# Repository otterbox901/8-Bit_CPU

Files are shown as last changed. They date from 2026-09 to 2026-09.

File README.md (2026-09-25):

# 8-Bit CPU

A microcoded 8-bit CPU built from 24 74HC-series logic and memory ICs: custom
instruction set, 4 general-purpose registers, add/subtract ALU with Zero and
Carry flags, and a control unit driven entirely by two EEPROMs.


*Preview from JLCPCB

## Status: In progress

- [x] Instruction set (10 instructions, 1- and 2-byte encodings)
- [x] Microcode ROM generator (`ROM/microcode_rom_gen.py`)
- [x] Emulator + assembler, full test program passing
- [x] Schematic: 24 ICs, 0 ERC errors
- [x] Schematic verified by simulation: the KiCad netlist runs the test program
      at the chip-pin level with the real ROM images (`kicad_files/sim_netlist.py`)
- [x] PCB: 2-layer, 160 × 140 mm, fully routed (Freerouting), GND pour on
      both layers; DRC clean (0 errors, 0 warnings, 0 unconnected) and 0
      schematic-parity differences
- [x] Fabrication outputs: Gerbers + drill (`fab/8-bit-cpu-gerbers.zip`),
      BOM and pick-and-place files
- [ ] Order boards, burn the EEPROMs, and bring up the hardware

## Overview

| | |
|---|---|
| Data path | 8-bit |
| Registers | R0–R3 (2 × 74HC670 register file), plus PC, MAR, IR, A, TEMP |
| Control unit | Microcoded: 2 × 28C256, addressed by opcode, 2-bit step, Z, C |
| ALU | Add, subtract (two's complement), Zero and Carry flags |
| Memory | Harvard: 256 B program EEPROM (28C64), 256 B data SRAM (6116) |
| Clock | 1 MHz canned oscillator (target 1–2 MHz), or external via jumper |
| IC count | 24 (+ oscillator) |
| Board | 2-layer, 160 × 140 mm, SMD logic; EEPROMs and SRAM in DIP sockets so they can be reprogrammed |
| Power | USB-C, 5 V, polyfuse |

## Instruction Set

| Opcode | Mnemonic | Bytes | Operation |
|---|---|---|---|
| `0000` | `NOP` | 1 | No operation |
| `0001` | `LOAD Rd, addr` | 2 | Rd ← RAM[addr] |
| `0010` | `STORE Rd, addr` | 2 | RAM[addr] ← Rd |
| `0011` | `ADD Rd, Rs` | 1 | Rd ← Rd + Rs (sets Z, C) |
| `0100` | `SUB Rd, Rs` | 1 | Rd ← Rd − Rs (sets Z, C; C=1 means no borrow) |
| `0101` | `JMP addr` | 2 | PC ← addr |
| `0110` | `JZ addr` | 2 | PC ← addr if Z |
| `0111` | `JC addr` | 2 | PC ← addr if C |
| `1000` | `MOV Rd, Rs` | 1 | Rd ← Rs |
| `1111` | `HLT` | 1 | Stop the clock |

Unused opcodes behave as `NOP`. Encoding: byte 0 is `[opcode:4][Rd:2][Rs:2]`;
address instructions add one address byte.

Every instruction takes 4 clock cycles (the 2-bit step counter wraps). Step 0
is always the fetch; conditional jumps are resolved by the control ROM, since
Z and C are part of its address.

## Control ROM

`ROM/microcode_rom_gen.py` walks all 256 `(opcode, step, Z, C)` addresses
and writes `microcode_table.csv` (human-readable) and `rom1.bin` / `rom2.bin`
(32 KB images for the two 28C256s). Active-low signals are stored inverted,
so the ROM outputs drive chip enable pins directly without inverter chips.

```bash
cd ROM && python3 microcode_rom_gen.py
```

## Emulator

`emulator.py` runs programs against `microcode_table.csv` directly, and
includes a two-pass assembler (labels, hex/decimal, `.byte`, `.ram addr, val`).

```bash
python3 emulator.py test_program.asm           # full ISA test, 6/6 checks
python3 emulator.py test_program.asm --trace-micro
python3 emulator.py -q test_program.asm        # results only
```

## Schematic

`kicad_files/8-bit cpu.kicad_sch` is **generated**: edit the `PARTS` tables in
`gen_schematic.py` and re-run it. It uses only KiCad's stock symbol and
footprint libraries, except for the 6116 symbol, which is embedded.

```bash
cd kicad_files
python3 gen_schematic.py     # rewrite the schematic
python3 sim_netlist.py       # run test_program.asm on the netlist itself
```

`sim_netlist.py` exports the netlist with `kicad-cli` and models every chip by
its datasheet pin numbers. It fails on bus contention, floating inputs, or
wrong results. Swapped bus bits and a stuck output enable were both confirmed
to be caught.

## PCB

### Ordering the board

Upload `fab/8-bit-cpu-gerbers.zip` to JLCPCB, PCBWay, etc. with:

| Setting | Value |
|---|---|
| Layers | 2 |
| Size | 160 × 140 mm |
| Thickness | 1.6 mm |
| Copper | 1 oz |
| Min track / space | 0.187 mm / 0.2 mm (standard service) |
| Min hole | 0.3 mm (vias 0.6 / 0.3 mm) |
| Plated slots | Yes: 4 on the USB-C shell (0.6 × 1.2 mm) |
| Surface finish | Any (HASL is fine) |

Checked before export: DRC with freshly refilled zones reports 0 errors, 0
warnings, 0 unconnected and 0 schematic-parity issues. The drill file holds
exactly the board's 454 plated holes (329 vias + 125 pads) plus 4 NPTH
mounting holes.

`fab/bom.csv` lists every part to solder. `fab/positions.csv` is the
pick-and-place file (origin at the board's bottom-left corner) for
assembled orders. **Not in the BOM, but needed:**

- 3 × 28-pin 600-mil DIP sockets (U1–U3) and 1 × 24-pin (U4). The
  EEPROMs have to come out to be programmed.
- 1 × 2.54 mm jumper shunt for J2 (pins 1–2 = on-board oscillator).
- The oscillator (Y1) must be a 7050-size, 5 V part with a **tri-state OE**
  on pin 1. HLT stops the clock through that pin.

To regenerate the outputs after a board change:

```bash
P="kicad_files/8-bit cpu.kicad_pcb"
kicad-cli pcb drc --refill-zones --schematic-parity "$P"
kicad-cli pcb export gerbers --layers F.Cu,B.Cu,F.Paste,B.Paste,F.Silkscreen,B.Silkscreen,F.Mask,B.Mask,Edge.Cuts --subtract-soldermask -o fab/gerbers/ "$P"
kicad-cli pcb export drill --format excellon --excellon-separate-th -u mm -o fab/gerbers/ "$P"
kicad-cli pcb export pos --format csv --units mm --side both --use-drill-file-origin -o fab/positions.csv "$P"
kicad-cli sch export bom --fields 'Reference,Value,Footprint,${QUANTITY}' --group-by 'Value,Footprint' -o fab/bom.csv "kicad_files/8-bit cpu.kicad_sch"
```

### Clock and timing

- Registers, PC and flags latch on CLK's **rising** edge.
- The step counter (U7) and a control-ROM address latch (U10, holding the
  opcode and flags) change on CLK's **falling** edge. The control word only
  changes while CLK is low and stays stable, glitch-free, while it's high.
- The two level-sensitive writes, RAM `/WE` and register-file `/Ew`, are
  `NAND(CLK, enable)`, so they only happen during that stable high phase.
- **HLT** drives the oscillator's OE low; the clock stops low (R2 pull-down).
  Reset restarts it.
- **Reset** (SW1, RC + Schmitt '14) asserts immediately but is only
  *released* on a falling clock edge, via U10 bit 6 and two '00 gates.
  Without this, a release while CLK is high skips the first fetch's PC
  increment. The netlist simulation found this bug.
- **J2 CLK SEL**: jumper 1-2 selects the on-board oscillator; 2-3 selects
  `EXT_CLK` for single-stepping from a button or microcontroller. HLT
  can't stop an external clock.
- **J3 DEBUG**: bus, CLK and GND for a logic analyser.

## Known Issues

- **Tracks go down to 0.15 mm** where the router threads between SOIC pins
  (min clearance 0.2 mm); fine for JLCPCB/PCBWay standard service.
- **74HC670 availability**: check stock before ordering; 74LS670 has the same
  pinout (mixing LS into an HC design is fine at these speeds).
- **ERC warnings** (no errors): "symbol doesn't match library" (the embedded
  copies are flattened), tri-state/output on the '245's input side, the
  `local` 6116 symbol, and the intentionally single-pin `EXT_CLK` label.
- No on-board regulator: the board runs straight off USB VBUS.
- Nothing has been tested on real hardware yet.

## Repo Contents

```
├── emulator.py              Microcode-driven emulator + assembler
├── test_program.asm         Full instruction-set test
├── ROM/
│   ├── microcode_rom_gen.py Control ROM generator
│   ├── microcode_table.csv  Human-readable ROM contents
│   └── rom1.bin rom2.bin    28C256 images
├── fab/
│   ├── 8-bit-cpu-gerbers.zip  Upload this to the board house
│   ├── gerbers/               Gerbers + Excellon drill files (+ job file)
│   ├── bom.csv                Bill of materials
│   └── positions.csv          Pick-and-place (board-corner origin)
└── kicad_files/
    ├── sim_netlist.py       Netlist-level simulation
    ├── 8-bit cpu.kicad_sch  Generated schematic
    ├── 8-bit cpu.kicad_pcb  Routed 2-layer board
    └── 8-bit cpu.kicad_pro  Project + design rules
```

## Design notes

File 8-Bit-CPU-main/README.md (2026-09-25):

# 8-Bit CPU

A microcoded 8-bit CPU built from 24 74HC-series logic and memory ICs: custom
instruction set, 4 general-purpose registers, add/subtract ALU with Zero and
Carry flags, and a control unit driven entirely by two EEPROMs.

This is the **downsized** design. The earlier 50-IC version (16-bit
addresses, AND/OR, a Negative flag, 3 control ROMs, and an AI-generated
schematic that needed many repair passes) is archived in git at commit
`3261fc8`.

## Status: In progress

- [x] Instruction set (10 instructions, 1- and 2-byte encodings)
- [x] Microcode ROM generator (`ROM/microcode_rom_gen.py`)
- [x] Emulator + assembler, full test program passing
- [x] Schematic: 24 ICs, generated from one netlist table
      (`kicad_files/gen_schematic.py`), 0 ERC errors
- [x] Schematic verified by simulation: the KiCad netlist runs the test program
      at the chip-pin level with the real ROM images (`kicad_files/sim_netlist.py`)
- [x] PCB: 2-layer, 160 × 140 mm, fully routed (Freerouting), GND pour on
      both layers; DRC clean (0 errors, 0 warnings, 0 unconnected) and 0
      schematic-parity differences
- [x] Fabrication outputs: Gerbers + drill (`fab/8-bit-cpu-gerbers.zip`),
      BOM and pick-and-place files
- [ ] Order boards, burn the EEPROMs, and bring up the hardware

## Overview

| | |
|---|---|
| Data path | 8-bit |
| Registers | R0–R3 (2 × 74HC670 register file), plus PC, MAR, IR, A, TEMP |
| Control unit | Microcoded: 2 × 28C256, addressed by opcode, 2-bit step, Z, C |
| ALU | Add, subtract (two's complement), Zero and Carry flags |
| Memory | Harvard: 256 B program EEPROM (28C64), 256 B data SRAM (6116) |
| Clock | 1 MHz canned oscillator (target 1–2 MHz), or external via jumper |
| IC count | 24 (+ oscillator) |
| Board | 2-layer, 160 × 140 mm, SMD logic; EEPROMs and SRAM in DIP sockets so they can be reprogrammed |
| Power | USB-C, 5 V, polyfuse |

## Instruction Set

| Opcode | Mnemonic | Bytes | Operation |
|---|---|---|---|
| `0000` | `NOP` | 1 | No operation |
| `0001` | `LOAD Rd, addr` | 2 | Rd ← RAM[addr] |
| `0010` | `STORE Rd, addr` | 2 | RAM[addr] ← Rd |
| `0011` | `ADD Rd, Rs` | 1 | Rd ← Rd + Rs (sets Z, C) |
| `0100` | `SUB Rd, Rs` | 1 | Rd ← Rd − Rs (sets Z, C; C=1 means no borrow) |
| `0101` | `JMP addr` | 2 | PC ← addr |
| `0110` | `JZ addr` | 2 | PC ← addr if Z |
| `0111` | `JC addr` | 2 | PC ← addr if C |
| `1000` | `MOV Rd, Rs` | 1 | Rd ← Rs |
| `1111` | `HLT` | 1 | Stop the clock |

Unused opcodes behave as `NOP`. Encoding: byte 0 is `[opcode:4][Rd:2][Rs:2]`;
address instructions add one address byte.

Every instruction takes 4 clock cycles (the 2-bit step counter wraps). Step 0
is always the fetch; conditional jumps are resolved by the control ROM, since
Z and C are part of its address.

## Control ROM

`ROM/microcode_rom_gen.py` walks all 256 `(opcode, step, Z, C)` addresses
and writes `microcode_table.csv` (human-readable) and `rom1.bin` / `rom2.bin`
(32 KB images for the two 28C256s). Active-low signals are stored inverted,
so the ROM outputs drive chip enable pins directly without inverter chips.

```bash
cd ROM && python3 microcode_rom_gen.py
```

## Emulator

`emulator.py` runs programs against `microcode_table.csv` directly, and
includes a two-pass assembler (labels, hex/decimal, `.byte`, `.ram addr, val`).

```bash
python3 emulator.py test_program.asm           # full ISA test, 6/6 checks
python3 emulator.py test_program.asm --trace-micro
python3 emulator.py -q test_program.asm        # results only
```

## Schematic

`kicad_files/8-bit cpu.kicad_sch` is **generated**: edit the `PARTS` tables in
`gen_schematic.py` and re-run it. It uses only KiCad's stock symbol and
footprint libraries, except for the 6116 symbol, which is embedded.

```bash
cd kicad_files
python3 gen_schematic.py     # rewrite the schematic
python3 sim_netlist.py       # run test_program.asm on the netlist itself
```

`sim_netlist.py` exports the netlist with `kicad-cli` and models every chip by
its datasheet pin numbers. It fails on bus contention, floating inputs, or
wrong results. Swapped bus bits and a stuck output enable were both confirmed
to be caught.

## PCB

`kicad_files/gen_pcb.py` builds the board from the schematic's netlist:

```bash
cd kicad_files
python3 gen_pcb.py place                          # new, unrouted board
python3 gen_pcb.py route --freerouting <path>     # autoroute + GND pours
python3 gen_pcb.py pour                           # redo pours only (keeps routing)
kicad-cli pcb drc --schematic-parity "8-bit cpu.kicad_pcb"
```

`place` overwrites any routing, so after hand-editing the board, use KiCad's
*Update PCB from Schematic* instead. Footprints are linked to their symbols,
and the schematic's symbol IDs stay the same when it's regenerated.
Placement lives in the `PLACEMENT` table. Each 100 nF cap sits right above
its IC's VCC pin. Power nets (+5V, GND, VBUS) use a 0.6 mm `Power` net class.

### Ordering the board

Upload `fab/8-bit-cpu-gerbers.zip` to JLCPCB, PCBWay, etc. with:

| Setting | Value |
|---|---|
| Layers | 2 |
| Size | 160 × 140 mm |
| Thickness | 1.6 mm |
| Copper | 1 oz |
| Min track / space | 0.187 mm / 0.2 mm (standard service) |
| Min hole | 0.3 mm (vias 0.6 / 0.3 mm) |
| Plated slots | Yes: 4 on the USB-C shell (0.6 × 1.2 mm) |
| Surface finish | Any (HASL is fine) |

Checked before export: DRC with freshly refilled zones reports 0 errors, 0
warnings, 0 unconnected and 0 schematic-parity issues. The drill file holds
exactly the board's 454 plated holes (329 vias + 125 pads) plus 4 NPTH
mounting holes.

`fab/bom.csv` lists every part to solder. `fab/positions.csv` is the
pick-and-place file (origin at the board's bottom-left corner) for
assembled orders. **Not in the BOM, but needed:**

- 3 × 28-pin 600-mil DIP sockets (U1–U3) and 1 × 24-pin (U4). The
  EEPROMs have to come out to be programmed.
- 1 × 2.54 mm jumper shunt for J2 (pins 1–2 = on-board oscillator).
- The oscillator (Y1) must be a 7050-size, 5 V part with a **tri-state OE**
  on pin 1. HLT stops the clock through that pin.

To regenerate the outputs after a board change:

```bash
P="kicad_files/8-bit cpu.kicad_pcb"
kicad-cli pcb drc --refill-zones --schematic-parity "$P"
kicad-cli pcb export gerbers --layers F.Cu,B.Cu,F.Paste,B.Paste,F.Silkscreen,B.Silkscreen,F.Mask,B.Mask,Edge.Cuts --subtract-soldermask -o fab/gerbers/ "$P"
kicad-cli pcb export drill --format excellon --excellon-separate-th -u mm -o fab/gerbers/ "$P"
kicad-cli pcb export pos --format csv --units mm --side both --use-drill-file-origin -o fab/positions.csv "$P"
kicad-cli sch export bom --fields 'Reference,Value,Footprint,${QUANTITY}' --group-by 'Value,Footprint' -o fab/bom.csv "kicad_files/8-bit cpu.kicad_sch"
```

### Clock and timing

- Registers, PC and flags latch on CLK's **rising** edge.
- The step counter (U7) and a control-ROM address latch (U10, holding the
  opcode and flags) change on CLK's **falling** edge. The control word only
  changes while CLK is low and stays stable, glitch-free, while it's high.
- The two level-sensitive writes, RAM `/WE` and register-file `/Ew`, are
  `NAND(CLK, enable)`, so they only happen during that stable high phase.
- **HLT** drives the oscillator's OE low; the clock stops low (R2 pull-down).
  Reset restarts it.
- **Reset** (SW1, RC + Schmitt '14) asserts immediately but is only
  *released* on a falling clock edge, via U10 bit 6 and two '00 gates.
  Without this, a release while CLK is high skips the first fetch's PC
  increment. The netlist simulation found this bug.
- **J2 CLK SEL**: jumper 1-2 selects the on-board oscillator; 2-3 selects
  `EXT_CLK` for single-stepping from a button or microcontroller. HLT
  can't stop an external clock.
- **J3 DEBUG**: bus, CLK and GND for a logic analyser.

## Known Issues

- **Tracks go down to 0.15 mm** where the router threads between SOIC pins
  (min clearance 0.2 mm); fine for JLCPCB/PCBWay standard service.
- **74HC670 availability**: check stock before ordering; 74LS670 has the same
  pinout (mixing LS into an HC design is fine at these speeds).
- **ERC warnings** (no errors): "symbol doesn't match library" (the embedded
  copies are flattened), tri-state/output on the '245's input side, the
  `local` 6116 symbol, and the intentionally single-pin `EXT_CLK` label.
- No on-board regulator: the board runs straight off USB VBUS.
- Nothing has been tested on real hardware yet.

## Repo Contents

```
├── emulator.py              Microcode-driven emulator + assembler
├── test_program.asm         Full instruction-set test
├── ROM/
│   ├── microcode_rom_gen.py Control ROM generator
│   ├── microcode_table.csv  Human-readable ROM contents
│   └── rom1.bin rom2.bin    28C256 images
├── fab/
│   ├── 8-bit-cpu-gerbers.zip  Upload this to the board house
│   ├── gerbers/               Gerbers + Excellon drill files (+ job file)
│   ├── bom.csv                Bill of materials
│   └── positions.csv          Pick-and-place (board-corner origin)
└── kicad_files/
    ├── gen_schematic.py     Schematic generator (the design source)
    ├── sim_netlist.py       Netlist-level simulation
    ├── gen_pcb.py           Board generator: placement, routing, pours
    ├── 8-bit cpu.kicad_sch  Generated schematic
    ├── 8-bit cpu.kicad_pcb  Routed 2-layer board
    └── 8-bit cpu.kicad_pro  Project + design rules (written by gen_pcb.py)
```

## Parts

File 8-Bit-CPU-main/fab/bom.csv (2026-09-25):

Reference | Value | Footprint | Qty
C1 | 1uF | Capacitor_SMD:C_0603_1608Metric | 1
C2 | 10uF | Capacitor_SMD:C_0805_2012Metric | 1
C10-C34 | 100nF | Capacitor_SMD:C_0603_1608Metric | 25
D1 | PWR | LED_SMD:LED_0603_1608Metric | 1
F1 | 750mA hold | Fuse:Fuse_1206_3216Metric | 1
J1 | USB-C 5V | Connector_USB:USB_C_Receptacle_GCT_USB4125-xx-x_6P_TopMnt_Horizontal | 1
J2 | CLK SEL | Connector_PinHeader_2.54mm:PinHeader_1x03_P2.54mm_Vertical | 1
J3 | DEBUG | Connector_PinHeader_2.54mm:PinHeader_1x10_P2.54mm_Vertical | 1
R1,R2 | 10k | Resistor_SMD:R_0603_1608Metric | 2
R3,R4 | 5.1k | Resistor_SMD:R_0603_1608Metric | 2
R5 | 1k | Resistor_SMD:R_0603_1608Metric | 1
RN1,RN2 | 10k x4 | Resistor_SMD:R_Array_Convex_4x0603 | 2
SW1 | RESET | Button_Switch_SMD:SW_SPST_TL3342 | 1
U1 | AT28C256 (ctrl ROM 1) | Package_DIP:DIP-28_W15.24mm_Socket | 1
U2 | AT28C256 (ctrl ROM 2) | Package_DIP:DIP-28_W15.24mm_Socket | 1
U3 | AT28C64B (program ROM) | Package_DIP:DIP-28_W15.24mm_Socket | 1
U4 | HM6116 (data RAM) | Package_DIP:DIP-24_W15.24mm_Socket | 1
U5 | 74HC161 (PC lo) | Package_SO:SOIC-16_3.9x9.9mm_P1.27mm | 1
U6 | 74HC161 (PC hi) | Package_SO:SOIC-16_3.9x9.9mm_P1.27mm | 1
U7 | 74HC161 | Package_SO:SOIC-16_3.9x9.9mm_P1.27mm | 1
U8 | 74HC377 (MAR) | Package_SO:SOIC-20W_7.5x12.8mm_P1.27mm | 1
U9 | 74HC377 (IR) | Package_SO:SOIC-20W_7.5x12.8mm_P1.27mm | 1
U10 | 74HC377 | Package_SO:SOIC-20W_7.5x12.8mm_P1.27mm | 1
U11 | 74HC377 (A) | Package_SO:SOIC-20W_7.5x12.8mm_P1.27mm | 1
U12 | 74HC377 (TEMP) | Package_SO:SOIC-20W_7.5x12.8mm_P1.27mm | 1
U13 | 74HC670 (R0-R3 bits 0-3) | Package_SO:SOIC-16_3.9x9.9mm_P1.27mm | 1
U14 | 74HC670 (R0-R3 bits 4-7) | Package_SO:SOIC-16_3.9x9.9mm_P1.27mm | 1
U15 | 74HC157 | Package_SO:SOIC-16_3.9x9.9mm_P1.27mm | 1
U16,U17 | 74HC86 | Package_SO:SOIC-14_3.9x8.7mm_P1.27mm | 2
U18,U19 | 74HC283 | Package_SO:SOIC-16_3.9x9.9mm_P1.27mm | 2
U20 | 74HC245 (ALU out) | Package_SO:SOIC-20W_7.5x12.8mm_P1.27mm | 1
U21 | 74HC688 (zero detect) | Package_SO:SOIC-20W_7.5x12.8mm_P1.27mm | 1
U22 | 74HC173 (flags) | Package_SO:SOIC-16_3.9x9.9mm_P1.27mm | 1
U23 | 74HC00 | Package_SO:SOIC-14_3.9x8.7mm_P1.27mm | 1
U24 | 74HC14 | Package_SO:SOIC-14_3.9x8.7mm_P1.27mm | 1
Y1 | 1MHz osc, tri-state OE | Oscillator:Oscillator_SMD_SeikoEpson_SG8002CA-4Pin_7.0x5.0mm | 1

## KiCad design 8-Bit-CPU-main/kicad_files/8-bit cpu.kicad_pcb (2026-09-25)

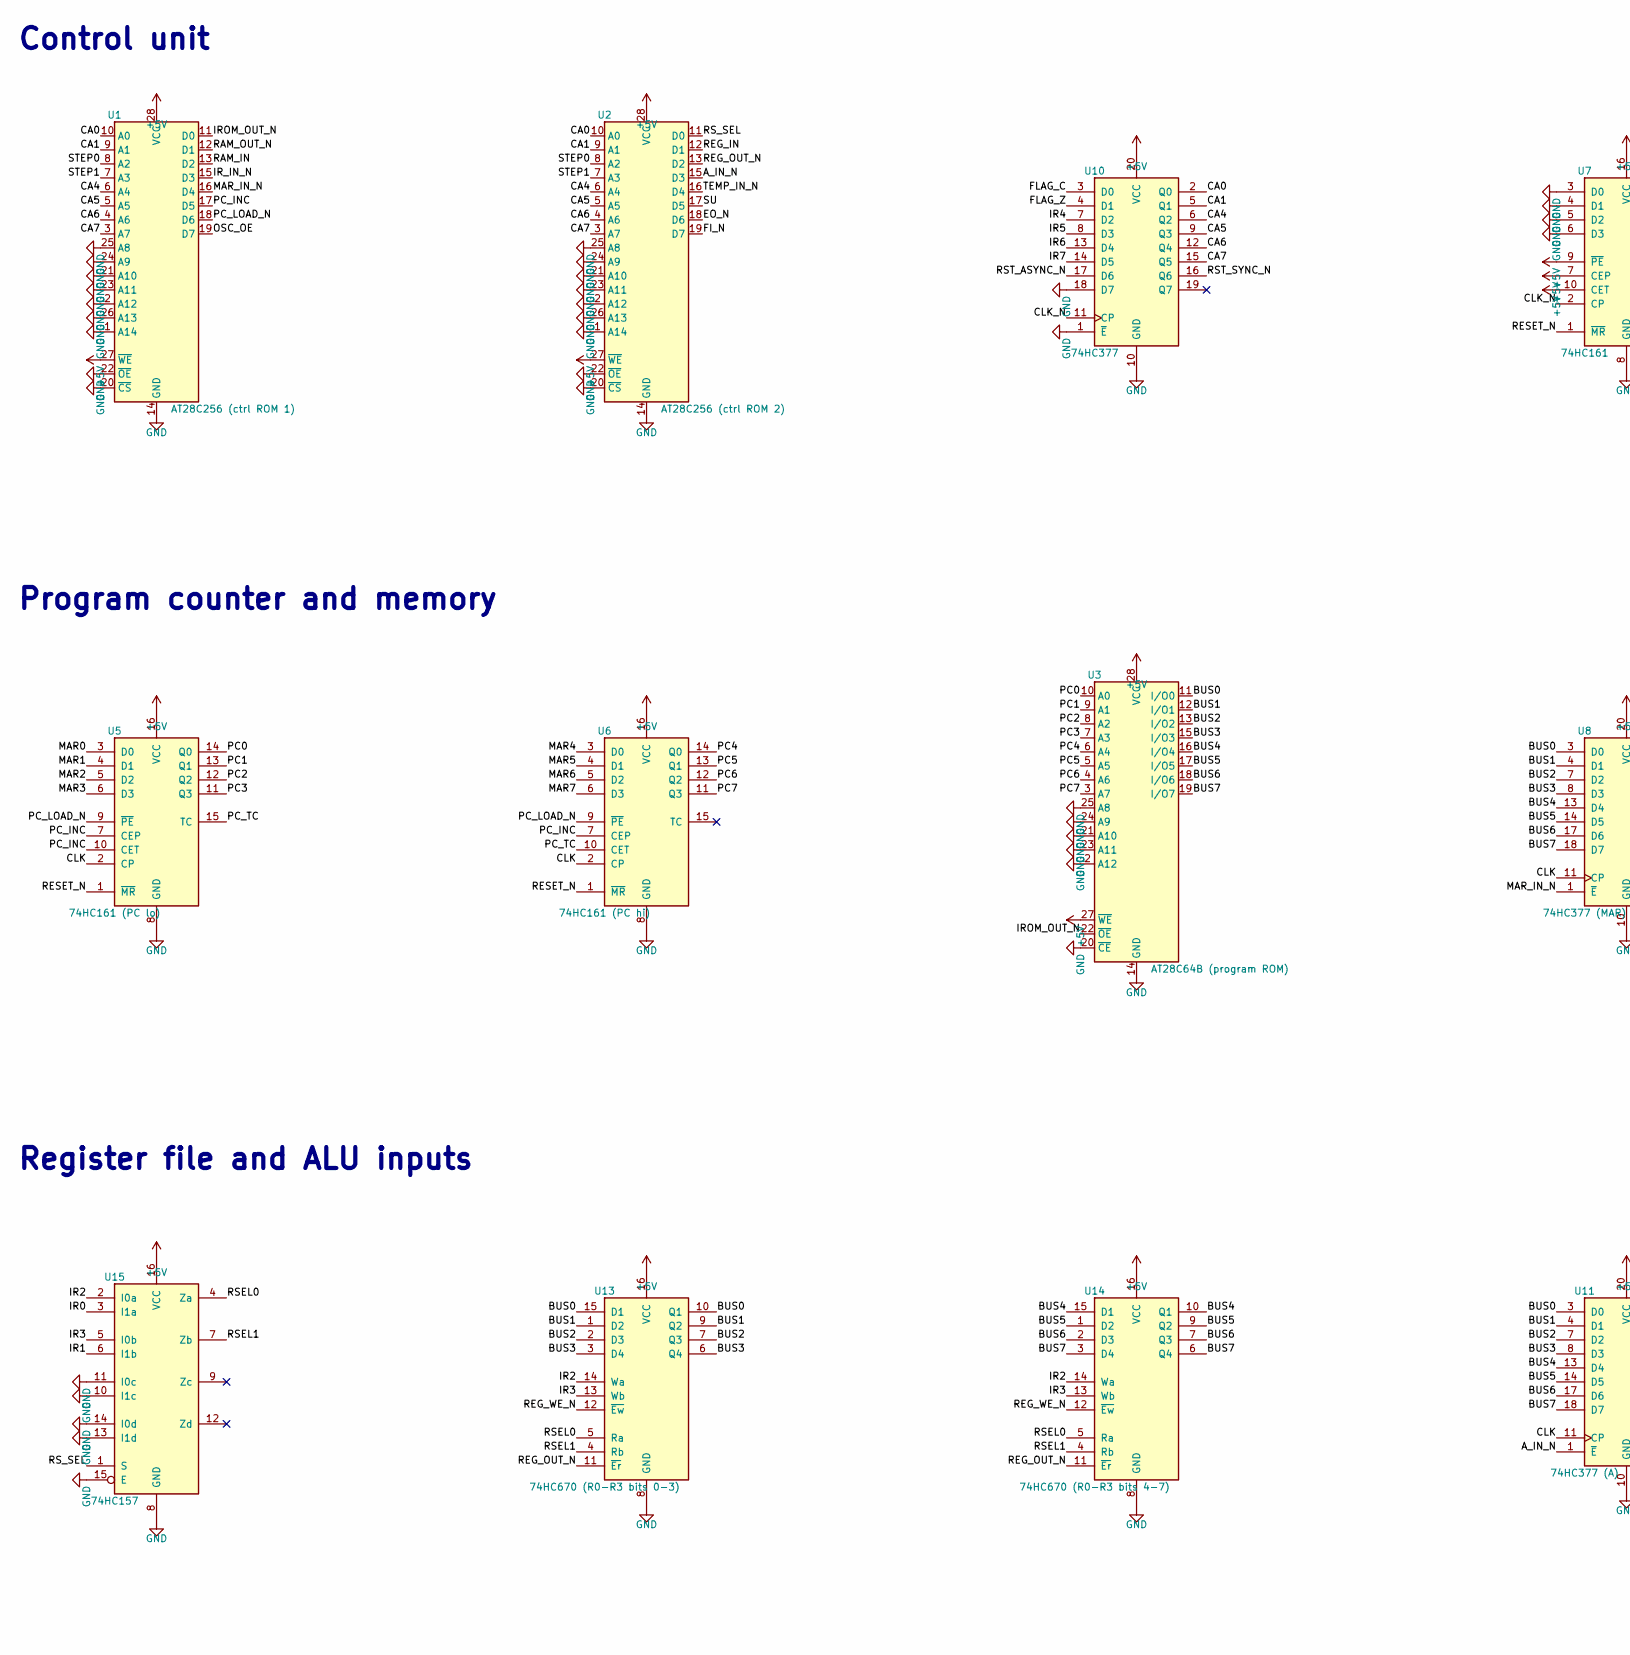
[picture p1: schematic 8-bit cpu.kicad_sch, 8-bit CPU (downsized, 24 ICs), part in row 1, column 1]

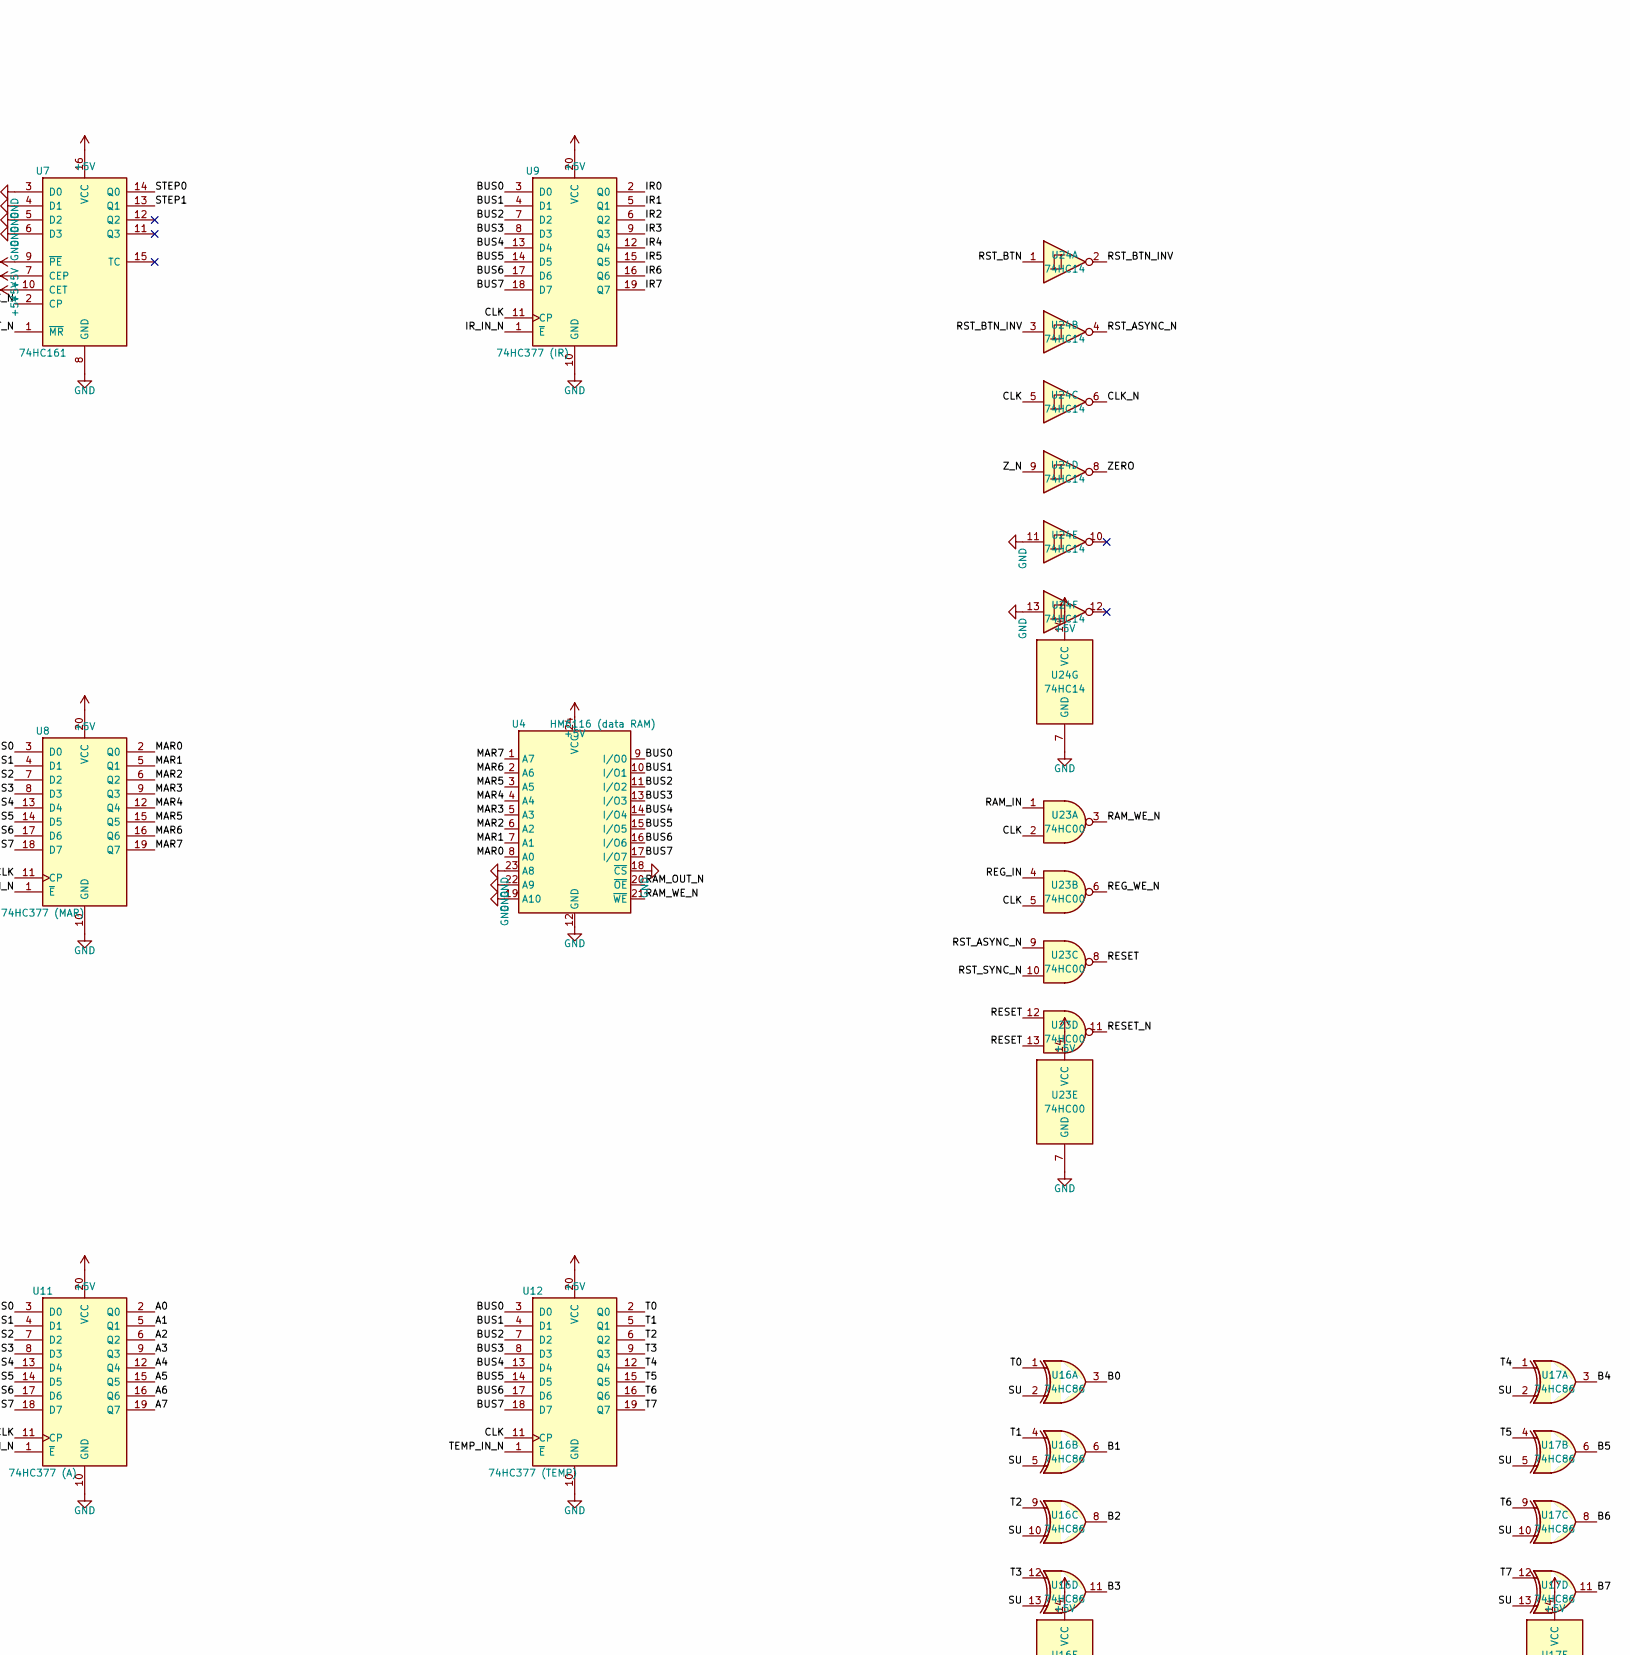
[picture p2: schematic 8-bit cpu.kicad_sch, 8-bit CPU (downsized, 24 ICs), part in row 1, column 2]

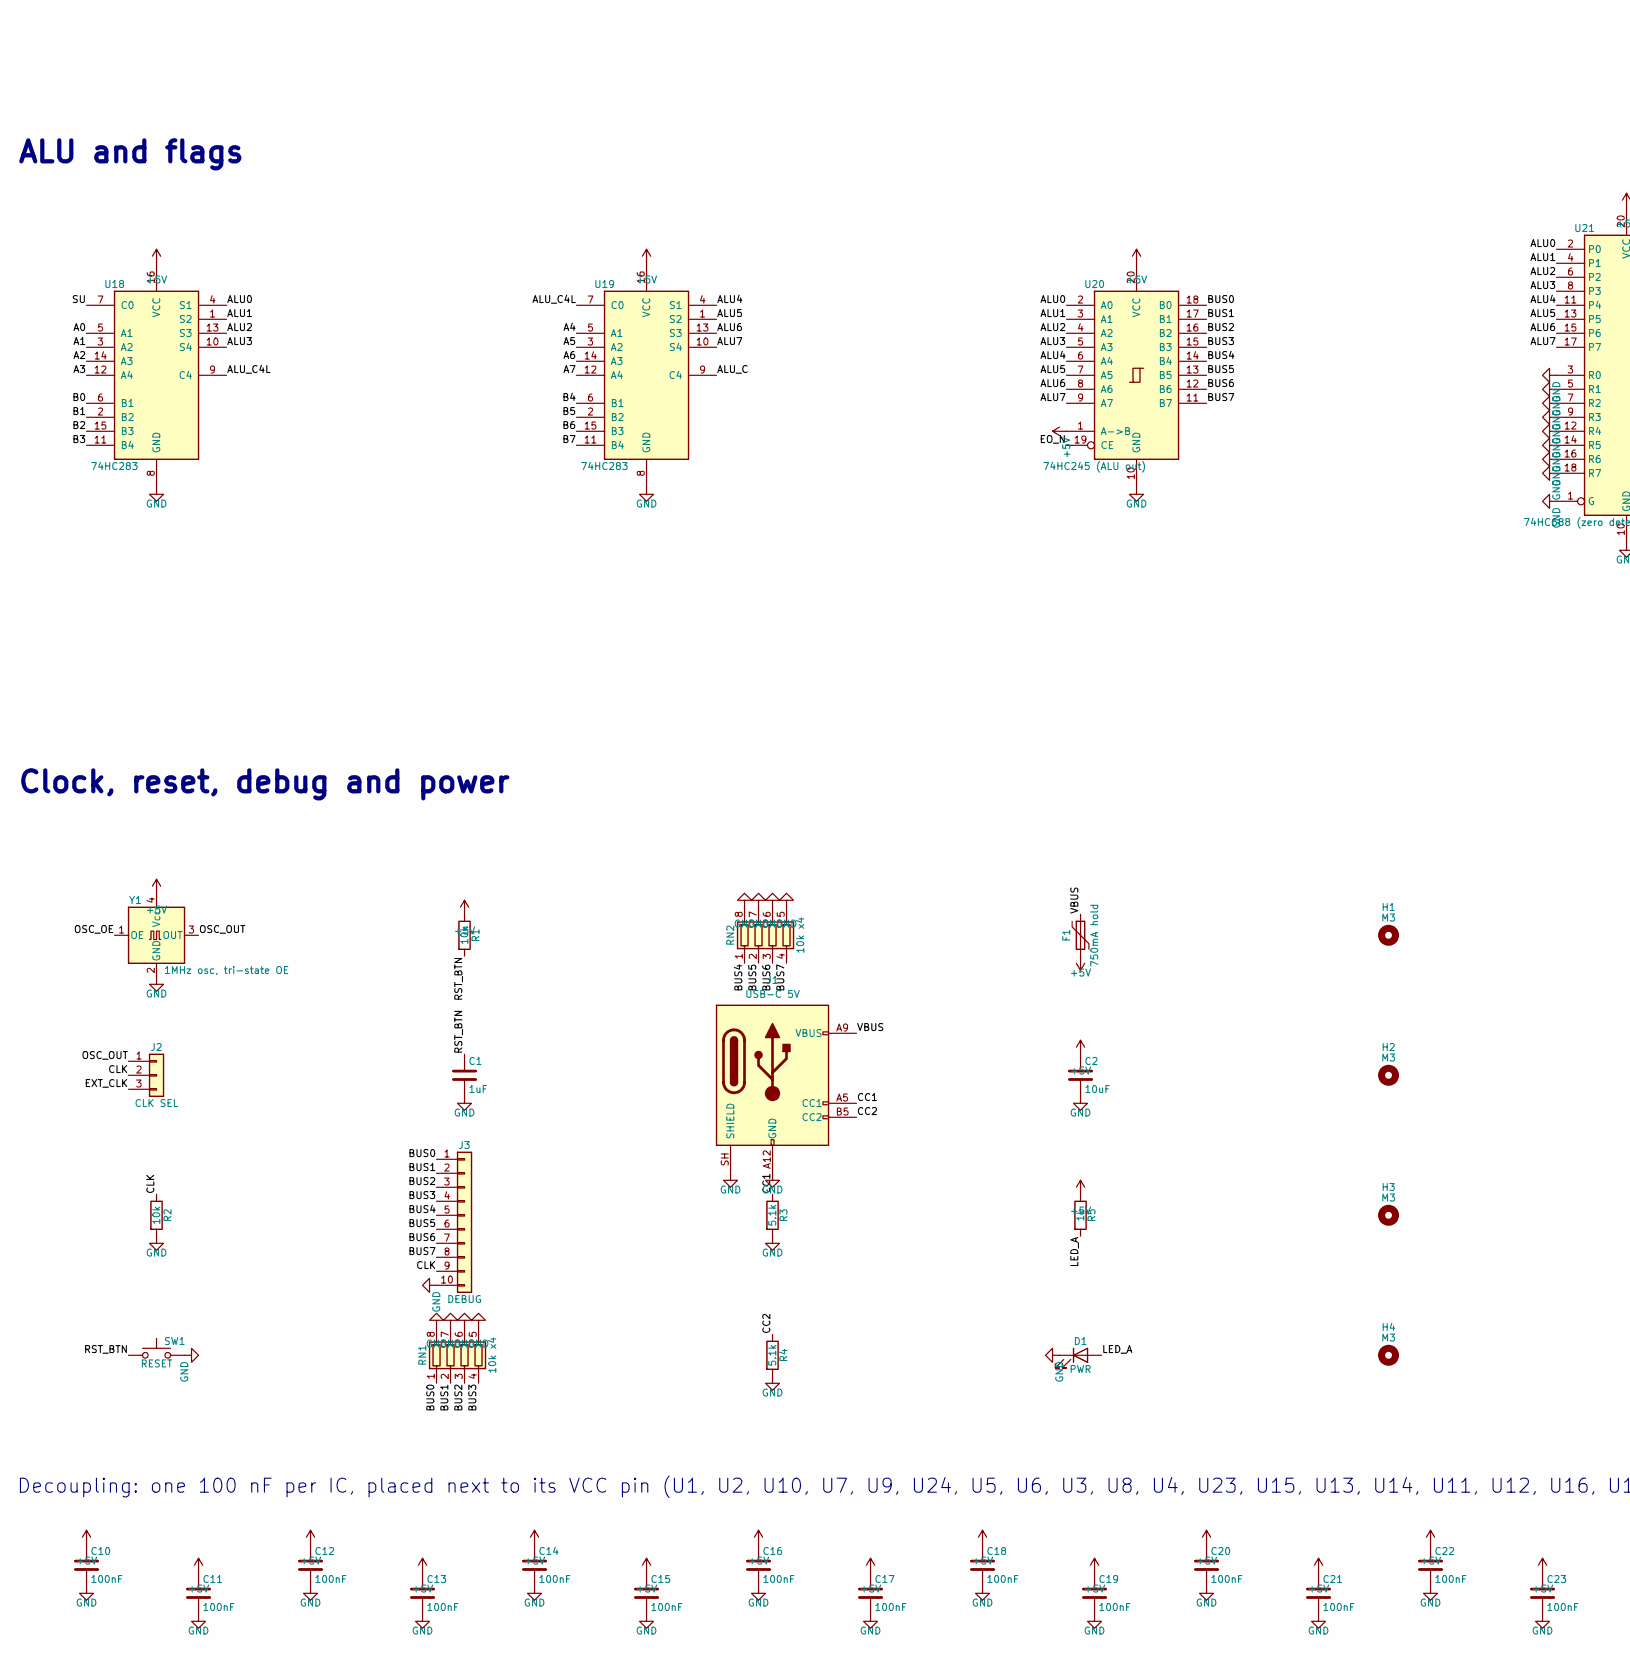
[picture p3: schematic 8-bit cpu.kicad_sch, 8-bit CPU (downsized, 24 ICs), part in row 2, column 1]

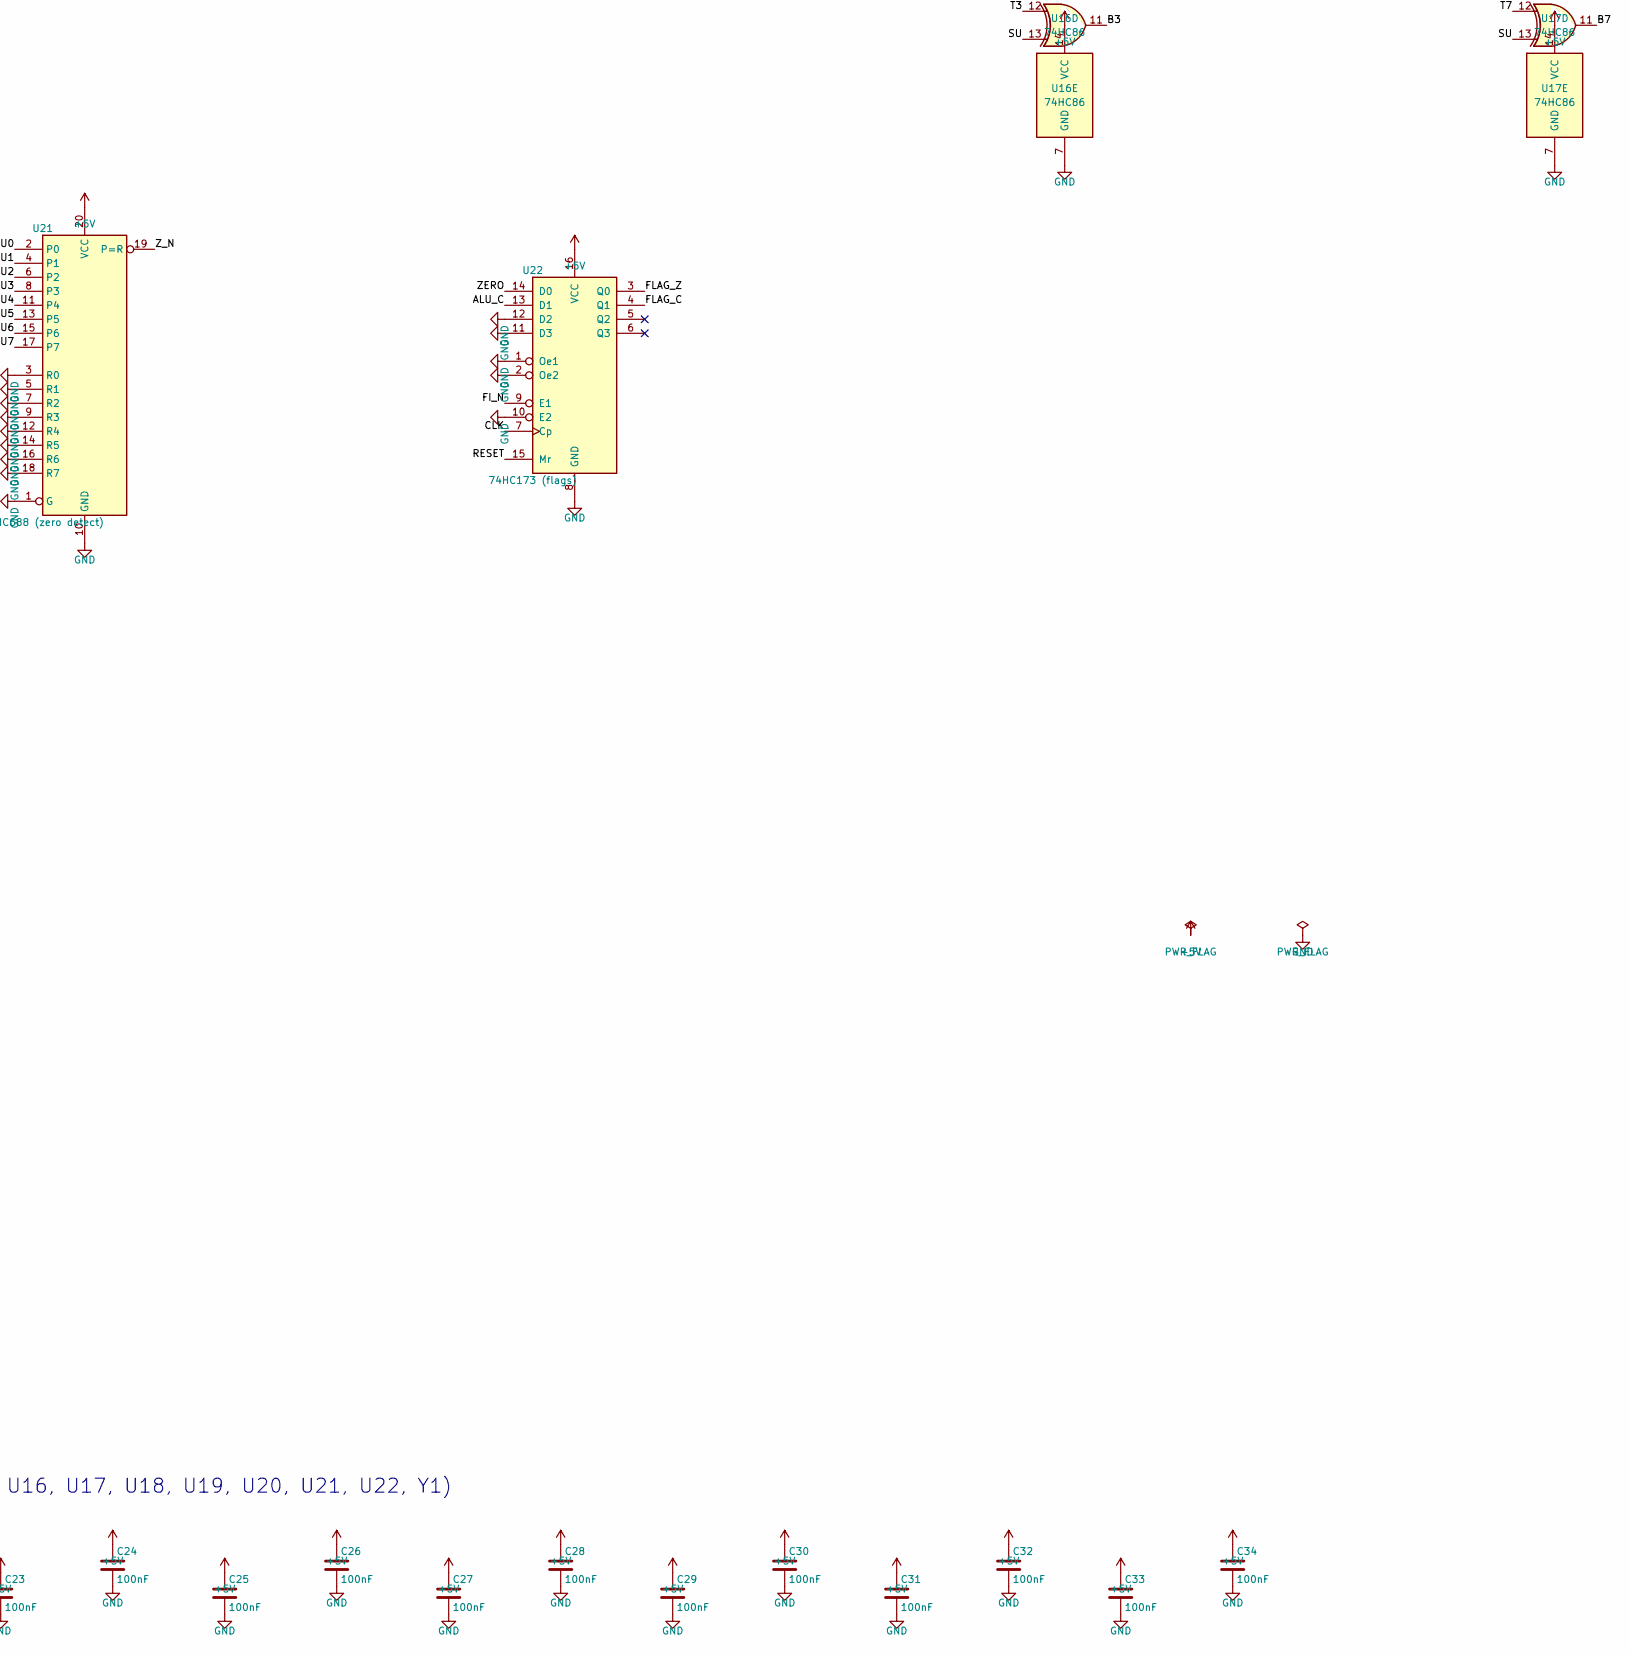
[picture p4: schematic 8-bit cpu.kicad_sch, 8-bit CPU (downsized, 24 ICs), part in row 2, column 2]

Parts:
C1: 1uF; C_0603_1608Metric
C2: 10uF; C_0805_2012Metric
C10, C11, C12, C13, C14, C15, C16, C17, C18, C19, C20, C21, C22, C23, C24, C25, C26, C27, C28, C29, C30, C31, C32, C33, C34: 100nF; C_0603_1608Metric
D1: PWR; LED_0603_1608Metric
F1: 750mA hold; Fuse_1206_3216Metric
H1, H2, H3, H4: M3; MountingHole_3.2mm_M3
J1: USB-C 5V; USB_C_Receptacle_GCT_USB4125-xx-x_6P_TopMnt_Horizontal
J2: CLK SEL; PinHeader_1x03_P2.54mm_Vertical
J3: DEBUG; PinHeader_1x10_P2.54mm_Vertical
R1, R2: 10k; R_0603_1608Metric
R3, R4: 5.1k; R_0603_1608Metric
R5: 1k; R_0603_1608Metric
RN1, RN2: 10k x4; R_Array_Convex_4x0603
SW1: RESET; SW_SPST_TL3342
U1: AT28C256 (ctrl ROM 1); DIP-28_W15.24mm_Socket
U2: AT28C256 (ctrl ROM 2); DIP-28_W15.24mm_Socket
U3: AT28C64B (program ROM); DIP-28_W15.24mm_Socket
U4: HM6116 (data RAM); DIP-24_W15.24mm_Socket
U5: 74HC161 (PC lo); SOIC-16_3.9x9.9mm_P1.27mm
U6: 74HC161 (PC hi); SOIC-16_3.9x9.9mm_P1.27mm
U7: 74HC161; SOIC-16_3.9x9.9mm_P1.27mm
U8: 74HC377 (MAR); SOIC-20W_7.5x12.8mm_P1.27mm
U9: 74HC377 (IR); SOIC-20W_7.5x12.8mm_P1.27mm
U10: 74HC377; SOIC-20W_7.5x12.8mm_P1.27mm
U11: 74HC377 (A); SOIC-20W_7.5x12.8mm_P1.27mm
U12: 74HC377 (TEMP); SOIC-20W_7.5x12.8mm_P1.27mm
U13: 74HC670 (R0-R3 bits 0-3); SOIC-16_3.9x9.9mm_P1.27mm
U14: 74HC670 (R0-R3 bits 4-7); SOIC-16_3.9x9.9mm_P1.27mm
U15: 74HC157; SOIC-16_3.9x9.9mm_P1.27mm
U16, U17: 74HC86; SOIC-14_3.9x8.7mm_P1.27mm
U18, U19: 74HC283; SOIC-16_3.9x9.9mm_P1.27mm
U20: 74HC245 (ALU out); SOIC-20W_7.5x12.8mm_P1.27mm
U21: 74HC688 (zero detect); SOIC-20W_7.5x12.8mm_P1.27mm
U22: 74HC173 (flags); SOIC-16_3.9x9.9mm_P1.27mm
U23: 74HC00; SOIC-14_3.9x8.7mm_P1.27mm
U24: 74HC14; SOIC-14_3.9x8.7mm_P1.27mm
Y1: 1MHz osc, tri-state OE; Oscillator_SMD_SeikoEpson_SG8002CA-4Pin_7.0x5.0mm

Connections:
+5V: C2.1, C10.1, C11.1, C12.1, C13.1, C14.1, C15.1, C16.1, C17.1, C18.1, C19.1, C20.1, C21.1, C22.1, C23.1, C24.1, C25.1, C26.1, C27.1, C28.1, C29.1, C30.1, C31.1, C32.1, C33.1, C34.1, F1.2, R1.1, R5.1, U1.27 (~WE), U1.28 (VCC), U2.27 (~WE), U2.28 (VCC), U3.27 (~WE), U3.28 (VCC), U4.24 (VCC), U5.16 (VCC), U6.16 (VCC), U7.7 (CEP), U7.9 (~PE), U7.10 (CET), U7.16 (VCC), U8.20 (VCC), U9.20 (VCC), U10.20 (VCC), U11.20 (VCC), U12.20 (VCC), U13.16 (VCC), U14.16 (VCC), U15.16 (VCC), U16.14 (VCC), U17.14 (VCC), U18.16 (VCC), U19.16 (VCC), U20.1 (A->B), U20.20 (VCC), U21.20 (VCC), U22.16 (VCC), U23.14 (VCC), U24.14 (VCC), Y1.4 (Vcc)
/A0: U11.2 (Q0), U18.5 (A1)
/A1: U11.5 (Q1), U18.3 (A2)
/A2: U11.6 (Q2), U18.14 (A3)
/A3: U11.9 (Q3), U18.12 (A4)
/A4: U11.12 (Q4), U19.5 (A1)
/A5: U11.15 (Q5), U19.3 (A2)
/A6: U11.16 (Q6), U19.14 (A3)
/A7: U11.19 (Q7), U19.12 (A4)
/ALU0: U18.4 (S1), U20.2 (A0), U21.2 (P0)
/ALU1: U18.1 (S2), U20.3 (A1), U21.4 (P1)
/ALU2: U18.13 (S3), U20.4 (A2), U21.6 (P2)
/ALU3: U18.10 (S4), U20.5 (A3), U21.8 (P3)
/ALU4: U19.4 (S1), U20.6 (A4), U21.11 (P4)
/ALU5: U19.1 (S2), U20.7 (A5), U21.13 (P5)
/ALU6: U19.13 (S3), U20.8 (A6), U21.15 (P6)
/ALU7: U19.10 (S4), U20.9 (A7), U21.17 (P7)
/ALU_C: U19.9 (C4), U22.13 (D1)
/ALU_C4L: U18.9 (C4), U19.7 (C0)
/A_IN_N: U2.15 (D3), U11.1 (~E)
/B0: U16.3, U18.6 (B1)
/B1: U16.6, U18.2 (B2)
/B2: U16.8, U18.15 (B3)
/B3: U16.11, U18.11 (B4)
/B4: U17.3, U19.6 (B1)
/B5: U17.6, U19.2 (B2)
/B6: U17.8, U19.15 (B3)
/B7: U17.11, U19.11 (B4)
/BUS0: J3.1, RN1.1 (R1.1), U3.11 (I/O0), U4.9 (I/O0), U8.3 (D0), U9.3 (D0), U11.3 (D0), U12.3 (D0), U13.10 (Q1), U13.15 (D1), U20.18 (B0)
/BUS1: J3.2, RN1.2 (R2.1), U3.12 (I/O1), U4.10 (I/O1), U8.4 (D1), U9.4 (D1), U11.4 (D1), U12.4 (D1), U13.1 (D2), U13.9 (Q2), U20.17 (B1)
/BUS2: J3.3, RN1.3 (R3.1), U3.13 (I/O2), U4.11 (I/O2), U8.7 (D2), U9.7 (D2), U11.7 (D2), U12.7 (D2), U13.2 (D3), U13.7 (Q3), U20.16 (B2)
/BUS3: J3.4, RN1.4 (R4.1), U3.15 (I/O3), U4.13 (I/O3), U8.8 (D3), U9.8 (D3), U11.8 (D3), U12.8 (D3), U13.3 (D4), U13.6 (Q4), U20.15 (B3)
/BUS4: J3.5, RN2.1 (R1.1), U3.16 (I/O4), U4.14 (I/O4), U8.13 (D4), U9.13 (D4), U11.13 (D4), U12.13 (D4), U14.10 (Q1), U14.15 (D1), U20.14 (B4)
/BUS5: J3.6, RN2.2 (R2.1), U3.17 (I/O5), U4.15 (I/O5), U8.14 (D5), U9.14 (D5), U11.14 (D5), U12.14 (D5), U14.1 (D2), U14.9 (Q2), U20.13 (B5)
/BUS6: J3.7, RN2.3 (R3.1), U3.18 (I/O6), U4.16 (I/O6), U8.17 (D6), U9.17 (D6), U11.17 (D6), U12.17 (D6), U14.2 (D3), U14.7 (Q3), U20.12 (B6)
/BUS7: J3.8, RN2.4 (R4.1), U3.19 (I/O7), U4.17 (I/O7), U8.18 (D7), U9.18 (D7), U11.18 (D7), U12.18 (D7), U14.3 (D4), U14.6 (Q4), U20.11 (B7)
/CA0: U1.10 (A0), U2.10 (A0), U10.2 (Q0)
/CA1: U1.9 (A1), U2.9 (A1), U10.5 (Q1)
/CA4: U1.6 (A4), U2.6 (A4), U10.6 (Q2)
/CA5: U1.5 (A5), U2.5 (A5), U10.9 (Q3)
/CA6: U1.4 (A6), U2.4 (A6), U10.12 (Q4)
/CA7: U1.3 (A7), U2.3 (A7), U10.15 (Q5)
/CC1: J1.A5 (CC1), R3.1
/CC2: J1.B5 (CC2), R4.1
/CLK: J2.2, J3.9, R2.1, U5.2 (CP), U6.2 (CP), U8.11 (CP), U9.11 (CP), U11.11 (CP), U12.11 (CP), U22.7 (Cp), U23.2, U23.5, U24.5
/CLK_N: U7.2 (CP), U10.11 (CP), U24.6
/EO_N: U2.18 (D6), U20.19 (CE)
/EXT_CLK: J2.3
/FI_N: U2.19 (D7), U22.9 (E1)
/FLAG_C: U10.3 (D0), U22.4 (Q1)
/FLAG_Z: U10.4 (D1), U22.3 (Q0)
/IR0: U9.2 (Q0), U15.3 (I1a)
/IR1: U9.5 (Q1), U15.6 (I1b)
/IR2: U9.6 (Q2), U13.14 (Wa), U14.14 (Wa), U15.2 (I0a)
/IR3: U9.9 (Q3), U13.13 (Wb), U14.13 (Wb), U15.5 (I0b)
/IR4: U9.12 (Q4), U10.7 (D2)
/IR5: U9.15 (Q5), U10.8 (D3)
/IR6: U9.16 (Q6), U10.13 (D4)
/IR7: U9.19 (Q7), U10.14 (D5)
/IROM_OUT_N: U1.11 (D0), U3.22 (~OE)
/IR_IN_N: U1.15 (D3), U9.1 (~E)
/LED_A: D1.2 (A), R5.2
/MAR0: U4.8 (A0), U5.3 (D0), U8.2 (Q0)
/MAR1: U4.7 (A1), U5.4 (D1), U8.5 (Q1)
/MAR2: U4.6 (A2), U5.5 (D2), U8.6 (Q2)
/MAR3: U4.5 (A3), U5.6 (D3), U8.9 (Q3)
/MAR4: U4.4 (A4), U6.3 (D0), U8.12 (Q4)
/MAR5: U4.3 (A5), U6.4 (D1), U8.15 (Q5)
/MAR6: U4.2 (A6), U6.5 (D2), U8.16 (Q6)
/MAR7: U4.1 (A7), U6.6 (D3), U8.19 (Q7)
/MAR_IN_N: U1.16 (D4), U8.1 (~E)
/OSC_OE: U1.19 (D7), Y1.1 (OE)
/OSC_OUT: J2.1, Y1.3 (OUT)
/PC0: U3.10 (A0), U5.14 (Q0)
/PC1: U3.9 (A1), U5.13 (Q1)
/PC2: U3.8 (A2), U5.12 (Q2)
/PC3: U3.7 (A3), U5.11 (Q3)
/PC4: U3.6 (A4), U6.14 (Q0)
/PC5: U3.5 (A5), U6.13 (Q1)
/PC6: U3.4 (A6), U6.12 (Q2)
/PC7: U3.3 (A7), U6.11 (Q3)
/PC_INC: U1.17 (D5), U5.7 (CEP), U5.10 (CET), U6.7 (CEP)
/PC_LOAD_N: U1.18 (D6), U5.9 (~PE), U6.9 (~PE)
/PC_TC: U5.15 (TC), U6.10 (CET)
/RAM_IN: U1.13 (D2), U23.1
/RAM_OUT_N: U1.12 (D1), U4.20 (~OE)
/RAM_WE_N: U4.21 (~WE), U23.3
/REG_IN: U2.12 (D1), U23.4
/REG_OUT_N: U2.13 (D2), U13.11 (~Er), U14.11 (~Er)
/REG_WE_N: U13.12 (~Ew), U14.12 (~Ew), U23.6
/RESET: U22.15 (Mr), U23.8, U23.12, U23.13
/RESET_N: U5.1 (~MR), U6.1 (~MR), U7.1 (~MR), U23.11
/RSEL0: U13.5 (Ra), U14.5 (Ra), U15.4 (Za)
/RSEL1: U13.4 (Rb), U14.4 (Rb), U15.7 (Zb)
/RST_ASYNC_N: U10.17 (D6), U23.9, U24.4
/RST_BTN: C1.1, R1.2, SW1.1, U24.1
/RST_BTN_INV: U24.2, U24.3
/RST_SYNC_N: U10.16 (Q6), U23.10
/RS_SEL: U2.11 (D0), U15.1 (S)
/STEP0: U1.8 (A2), U2.8 (A2), U7.14 (Q0)
/STEP1: U1.7 (A3), U2.7 (A3), U7.13 (Q1)
/SU: U2.17 (D5), U16.2, U16.5, U16.10, U16.13, U17.2, U17.5, U17.10, U17.13, U18.7 (C0)
/T0: U12.2 (Q0), U16.1
/T1: U12.5 (Q1), U16.4
/T2: U12.6 (Q2), U16.9
/T3: U12.9 (Q3), U16.12
/T4: U12.12 (Q4), U17.1
/T5: U12.15 (Q5), U17.4
/T6: U12.16 (Q6), U17.9
/T7: U12.19 (Q7), U17.12
/TEMP_IN_N: U2.16 (D4), U12.1 (~E)
/VBUS: F1.1, J1.A9 (VBUS), J1.B9 (VBUS)
/ZERO: U22.14 (D0), U24.8
/Z_N: U21.19 (P=R), U24.9
GND: C1.2, C2.2, C10.2, C11.2, C12.2, C13.2, C14.2, C15.2, C16.2, C17.2, C18.2, C19.2, C20.2, C21.2, C22.2, C23.2, C24.2, C25.2, C26.2, C27.2, C28.2, C29.2, C30.2, C31.2, C32.2, C33.2, C34.2, D1.1 (K), J1.A12 (GND), J1.B12 (GND), J1.SH (SHIELD), J3.10, R2.2, R3.2, R4.2, RN1.5 (R4.2), RN1.6 (R3.2), RN1.7 (R2.2), RN1.8 (R1.2), RN2.5 (R4.2), RN2.6 (R3.2), RN2.7 (R2.2), RN2.8 (R1.2), SW1.2, U1.1 (A14), U1.2 (A12), U1.14 (GND), U1.20 (~CS), U1.21 (A10), U1.22 (~OE), U1.23 (A11), U1.24 (A9), U1.25 (A8), U1.26 (A13), U2.1 (A14), U2.2 (A12), U2.14 (GND), U2.20 (~CS), U2.21 (A10), U2.22 (~OE), U2.23 (A11), U2.24 (A9), U2.25 (A8), U2.26 (A13), U3.2 (A12), U3.14 (GND), U3.20 (~CE), U3.21 (A10), U3.23 (A11), U3.24 (A9), U3.25 (A8), U4.12 (GND), U4.18 (~CS), U4.19 (A10), U4.22 (A9), U4.23 (A8), U5.8 (GND), U6.8 (GND), U7.3 (D0), U7.4 (D1), U7.5 (D2), U7.6 (D3), U7.8 (GND), U8.10 (GND), U9.10 (GND), U10.1 (~E), U10.10 (GND), U10.18 (D7), U11.10 (GND), U12.10 (GND), U13.8 (GND), U14.8 (GND), U15.8 (GND), U15.10 (I1c), U15.11 (I0c), U15.13 (I1d), U15.14 (I0d), U15.15 (E), U16.7 (GND), U17.7 (GND), U18.8 (GND), U19.8 (GND), U20.10 (GND), U21.1 (G), U21.3 (R0), U21.5 (R1), U21.7 (R2), U21.9 (R3), U21.10 (GND), U21.12 (R4), U21.14 (R5), U21.16 (R6), U21.18 (R7), U22.1 (Oe1), U22.2 (Oe2), U22.8 (GND), U22.10 (E2), U22.11 (D3), U22.12 (D2), U23.7 (GND), U24.7 (GND), U24.11, U24.13, Y1.2 (GND)

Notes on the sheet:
Control unit
Program counter and memory
Register file and ALU inputs
ALU and flags
Clock, reset, debug and power
Decoupling: one 100 nF per IC, placed next to its VCC pin (U1, U2, U10, U7, U9, U24, U5, U6, U3, U8, U4, U23, U15, U13, U14, U11, U12, U16, U17, U18, U19, U20, U21, U22, Y1)

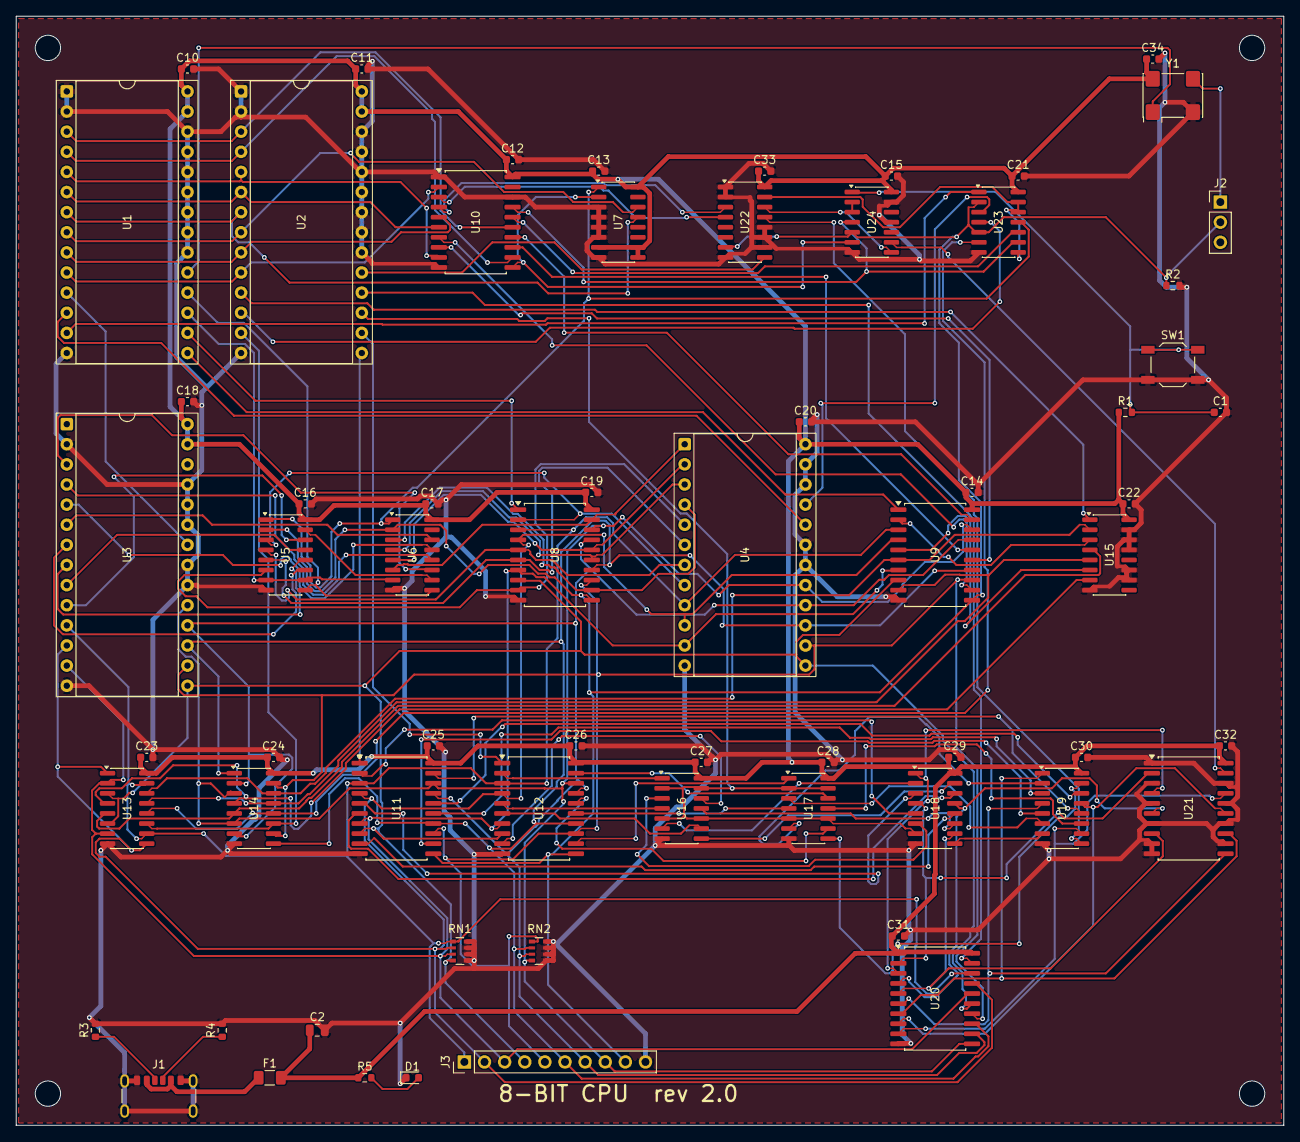
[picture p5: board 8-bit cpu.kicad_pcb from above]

Board: 2 copper layers, 160.0 x 140.0 mm, 69 parts (0 on the bottom side), 114 nets.
